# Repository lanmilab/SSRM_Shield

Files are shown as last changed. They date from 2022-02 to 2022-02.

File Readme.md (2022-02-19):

# IoT Solid State Ralay and Power Monitor Shield

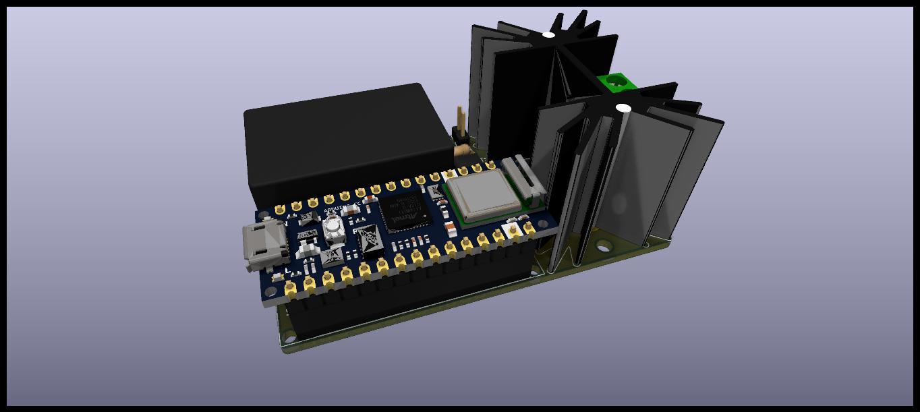
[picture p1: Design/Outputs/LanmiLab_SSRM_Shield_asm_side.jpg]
LanmiLab_SSRM_Shield_asm_side


Shield made specifically for Arduino nano IoT or compatible development board.
- Based on triac transistor with opto-isolated driving to be used for heater or lighting control IoT applications.
- Isolated 2Watts AC/DC converter.
- Integrates AC power monitor ACS71020KMABTR-030B3-I2C.
- One on board NTC temperature sensor, plus header for off-board NTC. 

## License

KiCad design is available but not verified, use on your own resposibility!

THE DESIGN IS PROVIDED "AS IS" AND THE AUTHOR DISCLAIMS ALL WARRANTIES WITH REGARD TO THIS DESIGN INCLUDING ALL IMPLIED WARRANTIES OF MERCHANTABILITY AND FITNESS. IN NO EVENT SHALL THE AUTHOR BE LIABLE FOR ANY SPECIAL, DIRECT, INDIRECT, OR CONSEQUENTIAL DAMAGES OR ANY DAMAGES WHATSOEVER RESULTING FROM LOSS OF USE, DATA OR PROFITS, WHETHER IN AN ACTION OF CONTRACT, NEGLIGENCE OR OTHER TORTIOUS ACTION, ARISING OUT OF OR IN CONNECTION WITH THE USE OR PERFORMANCE OF THIS DESIGN.

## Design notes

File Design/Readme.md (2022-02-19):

# IoT Solid State Ralay and Power Monitor Shield KiCad Design Files

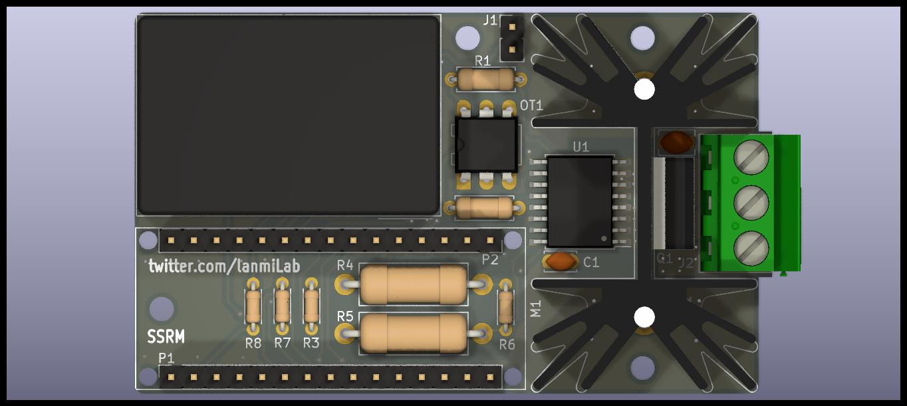
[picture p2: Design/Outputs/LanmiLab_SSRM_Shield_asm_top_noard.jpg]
LanmiLab_SSRM_Shield_asm_top_noard


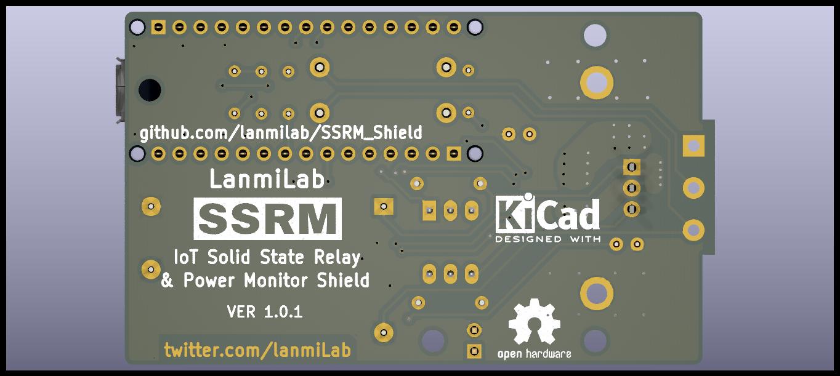
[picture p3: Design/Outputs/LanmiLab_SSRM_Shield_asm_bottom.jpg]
LanmiLab_SSRM_Shield_asm_bottom


Gerber and assembly files available in Outputs directory.

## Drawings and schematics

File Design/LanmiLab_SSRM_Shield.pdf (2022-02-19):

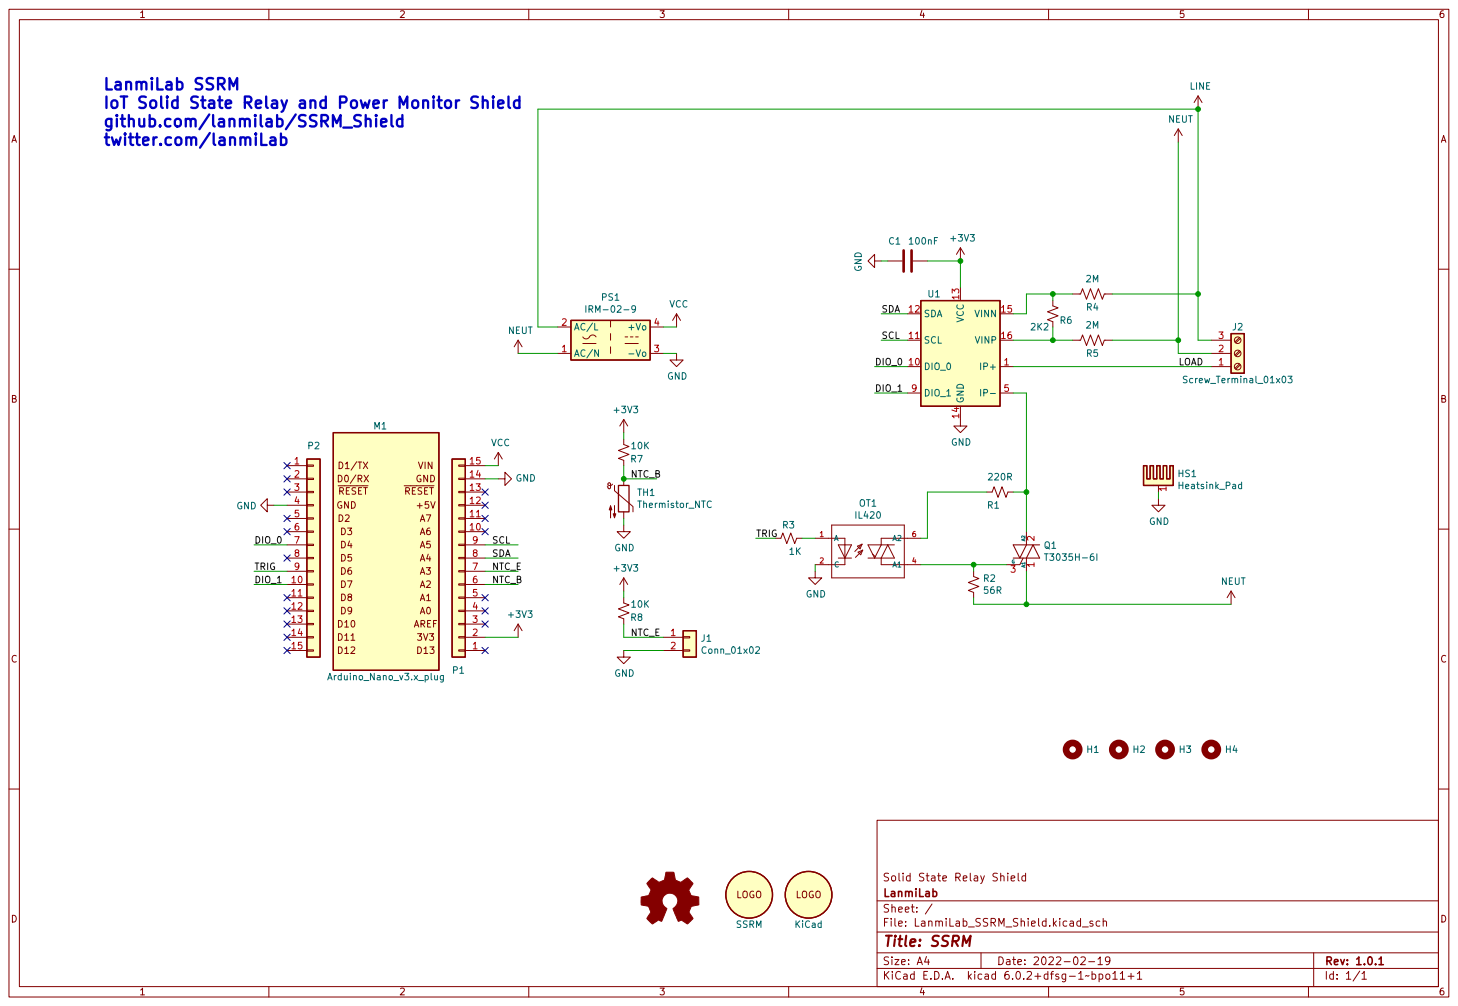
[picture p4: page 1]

DIO_0 DIO_1 LanmiLab SSRM
IoT Solid State Relay and Power Monitor Shield
github.com/lanmilab/SSRM_Shield
twitter.com/lanmiLab

File: LanmiLab_SSRM_Shield.kicad_sch Sheet: / LanmiLab Solid State Relay Shield

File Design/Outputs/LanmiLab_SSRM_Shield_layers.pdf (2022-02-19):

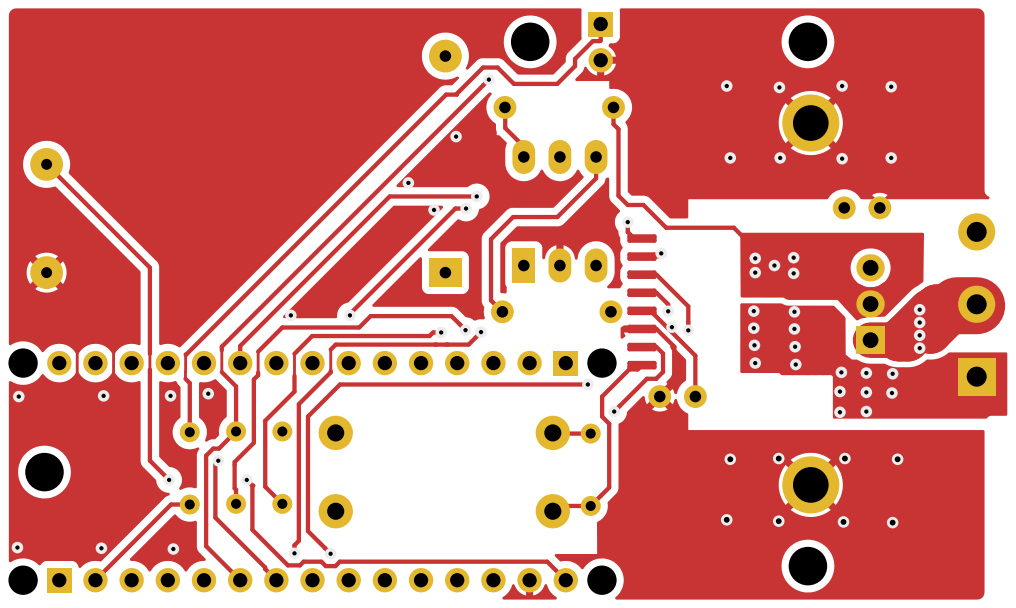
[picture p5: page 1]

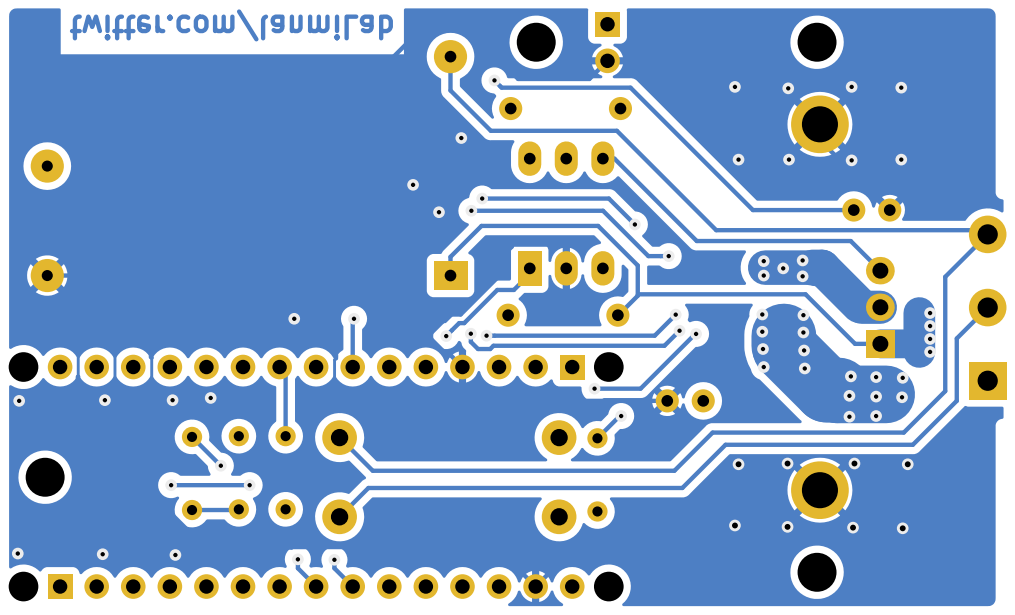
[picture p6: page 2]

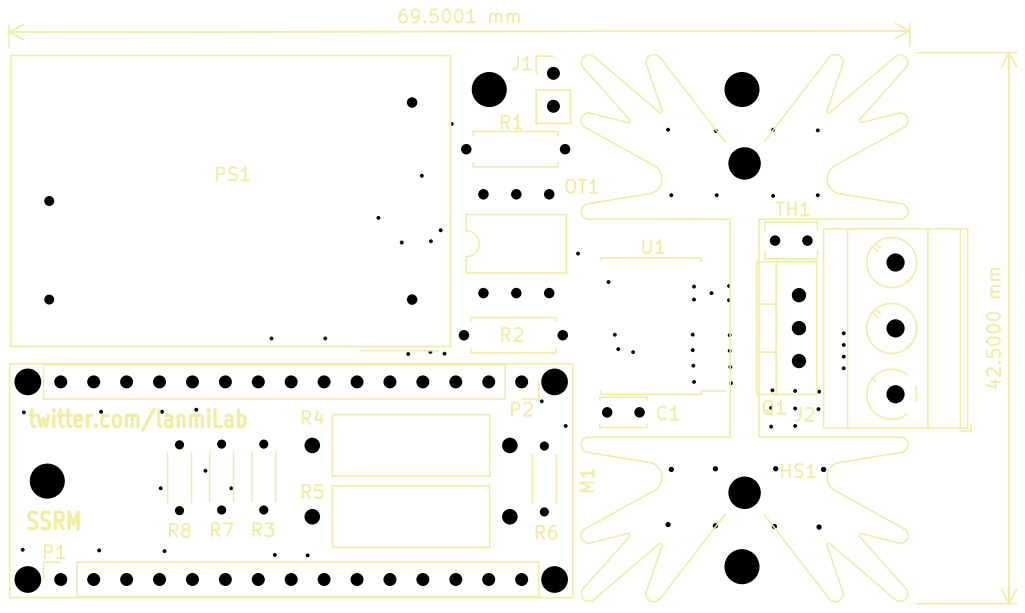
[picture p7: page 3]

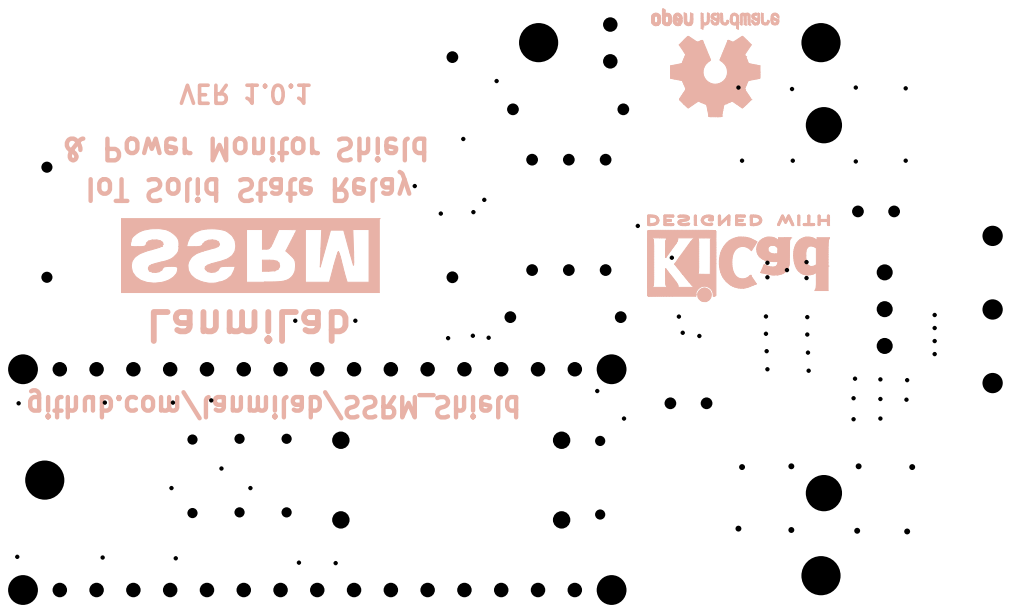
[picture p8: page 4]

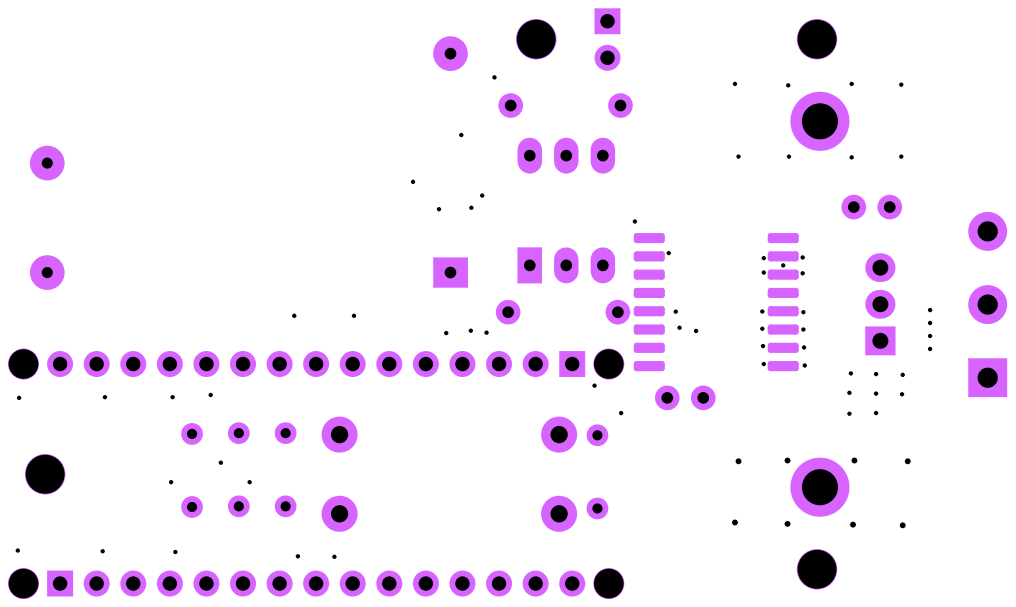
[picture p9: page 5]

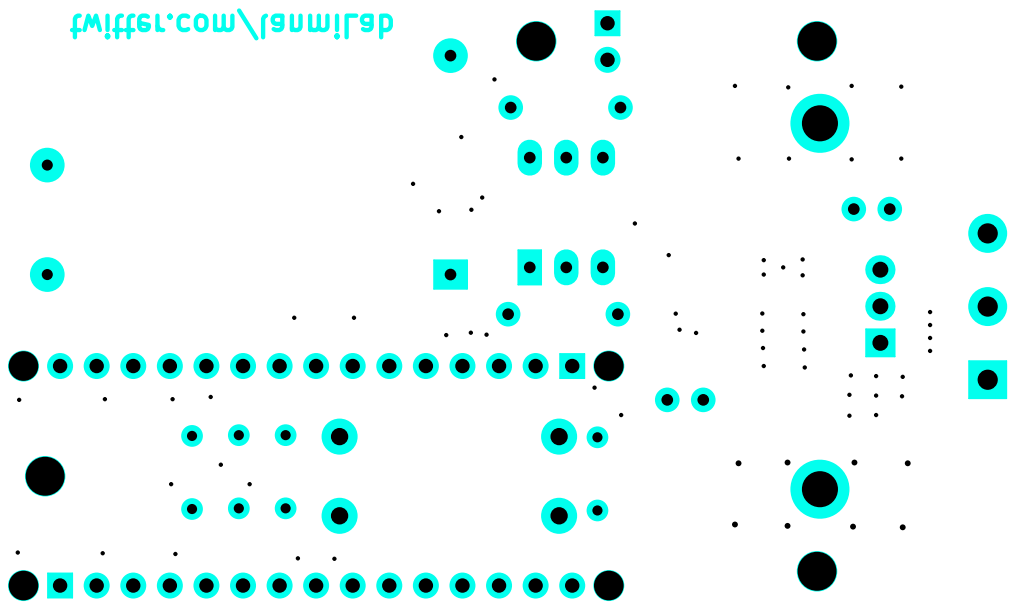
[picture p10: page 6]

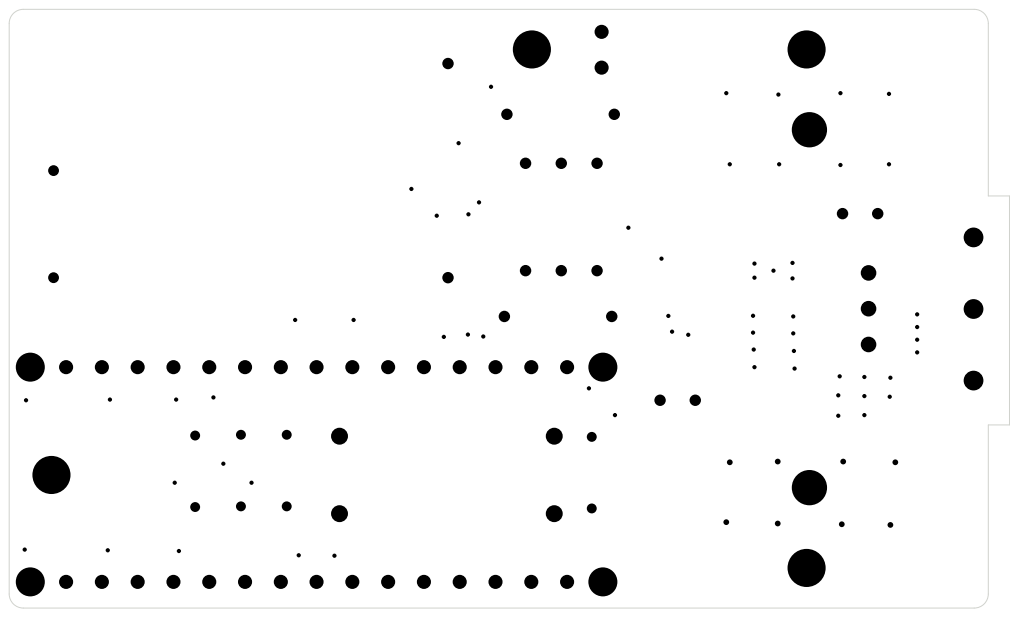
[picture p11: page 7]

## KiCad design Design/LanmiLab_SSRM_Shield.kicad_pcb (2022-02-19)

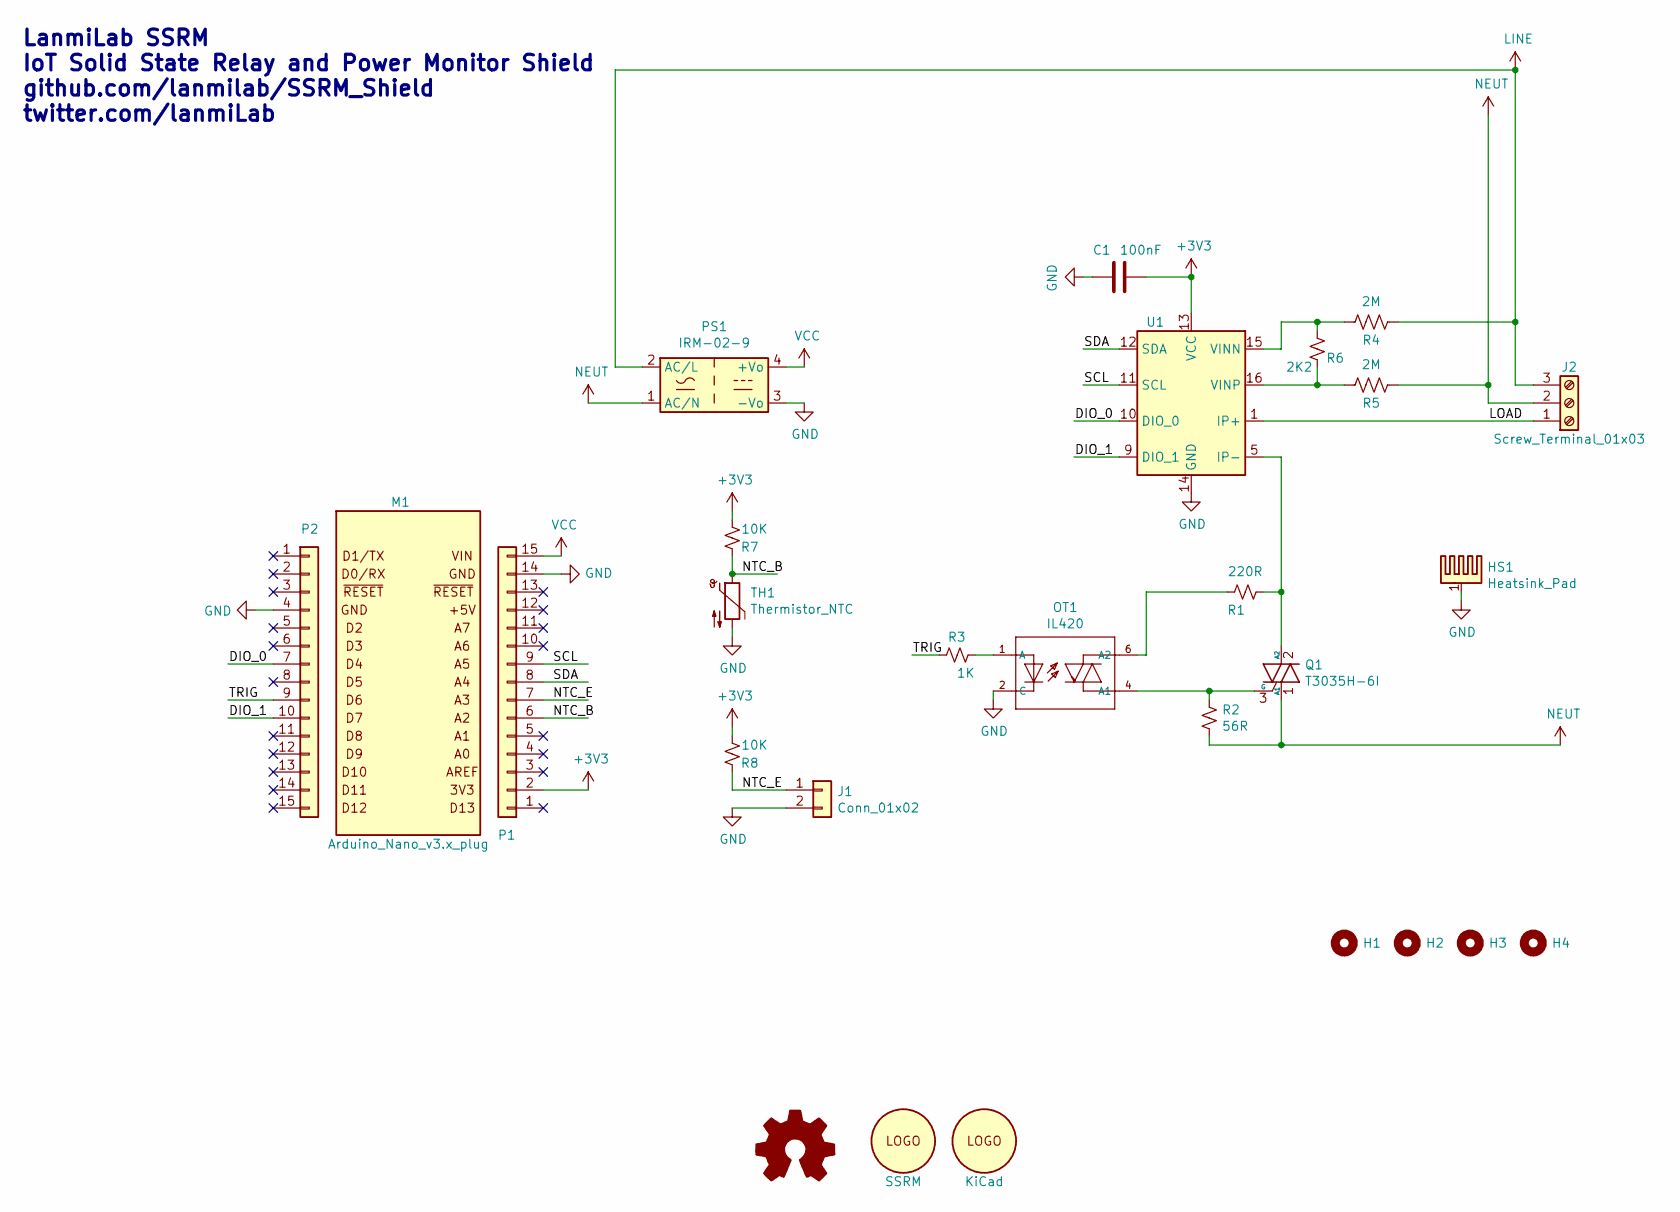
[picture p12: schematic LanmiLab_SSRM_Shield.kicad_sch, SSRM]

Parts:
C1: 100nF; C_Disc_D3.4mm_W2.1mm_P2.50mm; Part Number K104K15X7RF53L2
H1, H2, H3, H4: MountingHole; MountingHole_2.7mm_M2.5
HS1: Heatsink_Pad; Heatsink_Fischer_SK129-STS_42x25mm_2xDrill2.5mm; Part Number FA-T220-25E
J1: Conn_01x02; PinHeader_1x02_P2.54mm_Vertical; Part Number M20-9990245
J2: Screw_Terminal_01x03; TerminalBlock_MetzConnect_Type073_RT02603HBLU_1x03_P5.08mm_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; Part Number MKDS 3/ 3-5,08
LOGO1: Logo_Open_Hardware_Small; OSHW-Logo2_9.8x8mm_SilkScreen
LOGO2: SSRM; ssr
LOGO3: KiCad; KiCad-Logo2_5mm_SilkScreen
M1: Arduino_Nano_v3.x_plug; Arduino_Nano_33_IoT_3D_NoPads
OT1: IL420; DIP-6_W7.62mm_LongPads; Part Number IL420
P1, P2: Conn_01x15; PinSocket_1x15_P2.54mm_Vertical; Part Number PPPC151LFBN-RC
PS1: IRM-02-9; Converter_ACDC_MeanWell_IRM-02-xx_THT; Part Number IRM-02-9
Q1: T3035H-6I; TO-220-3_Vertical; Part Number T3035H-6I
R1: 220R; R_Axial_DIN0207_L6.3mm_D2.5mm_P7.62mm_Horizontal; Part Number MFP1-220R JI
R2: 56R; R_Axial_DIN0207_L6.3mm_D2.5mm_P7.62mm_Horizontal; Part Number MRS25000C5609FCT00
R3: 1K; R_Axial_DIN0204_L3.6mm_D1.6mm_P5.08mm_Horizontal; Part Number LR0204F1K0
R4, R5: 2M; R_Axial_DIN0414_L11.9mm_D4.5mm_P15.24mm_Horizontal; Part Number HVR3700002004FR500
R6: 2K2; R_Axial_DIN0204_L3.6mm_D1.6mm_P5.08mm_Horizontal; Part Number CFR16J2K2
R7, R8: 10K; R_Axial_DIN0204_L3.6mm_D1.6mm_P5.08mm_Horizontal; Part Number CFR16J10K
TH1: Thermistor_NTC; C_Disc_D3.8mm_W2.6mm_P2.50mm; Part Number B57891M0103K000
U1: ACS71020KMABTR-030B3-I2C; SOIC-16W_7.5x10.3mm_P1.27mm; Part Number ACS71020KMABTR-030B3-I2C

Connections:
+3V3: C1.1, P1.2, R7.2, R8.2, U1.13 (VCC)
/DIO_0: P2.7, U1.10 (DIO_0)
/DIO_1: P2.10, U1.9 (DIO_1)
/LOAD: J2.1, U1.1 (IP+), U1.2 (IP+), U1.3 (IP+), U1.4 (IP+)
/NTC_B: P1.6, R7.1, TH1.1
/NTC_E: J1.1, P1.7, R8.1
/SCL: P1.9, U1.11 (SCL)
/SDA: P1.8, U1.12 (SDA)
/TRIG: P2.9, R3.1
GND: C1.2, HS1.1, J1.2, OT1.2 (C), P1.14, P2.4, PS1.3 (-Vo), TH1.2, U1.14 (GND)
LINE: J2.3, PS1.2 (AC/L), R4.1
NEUT: J2.2, PS1.1 (AC/N), Q1.1 (A1), R2.2, R5.1
unnamed: OT1.1 (A), R3.2
unnamed: OT1.4 (A1), Q1.3 (G), R2.1
unnamed: OT1.6 (A2), R1.2
unnamed: Q1.2 (A2), R1.1, U1.5 (IP-), U1.6 (IP-), U1.7 (IP-), U1.8 (IP-)
unnamed: R4.2, R6.1, U1.15 (VINN)
unnamed: R5.2, R6.2, U1.16 (VINP)
VCC: P1.15, PS1.4 (+Vo)

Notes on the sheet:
LanmiLab SSRM IoT Solid State Relay and Power Monitor Shield github.com/lanmilab/SSRM_Shield twitter.com/lanmiLab

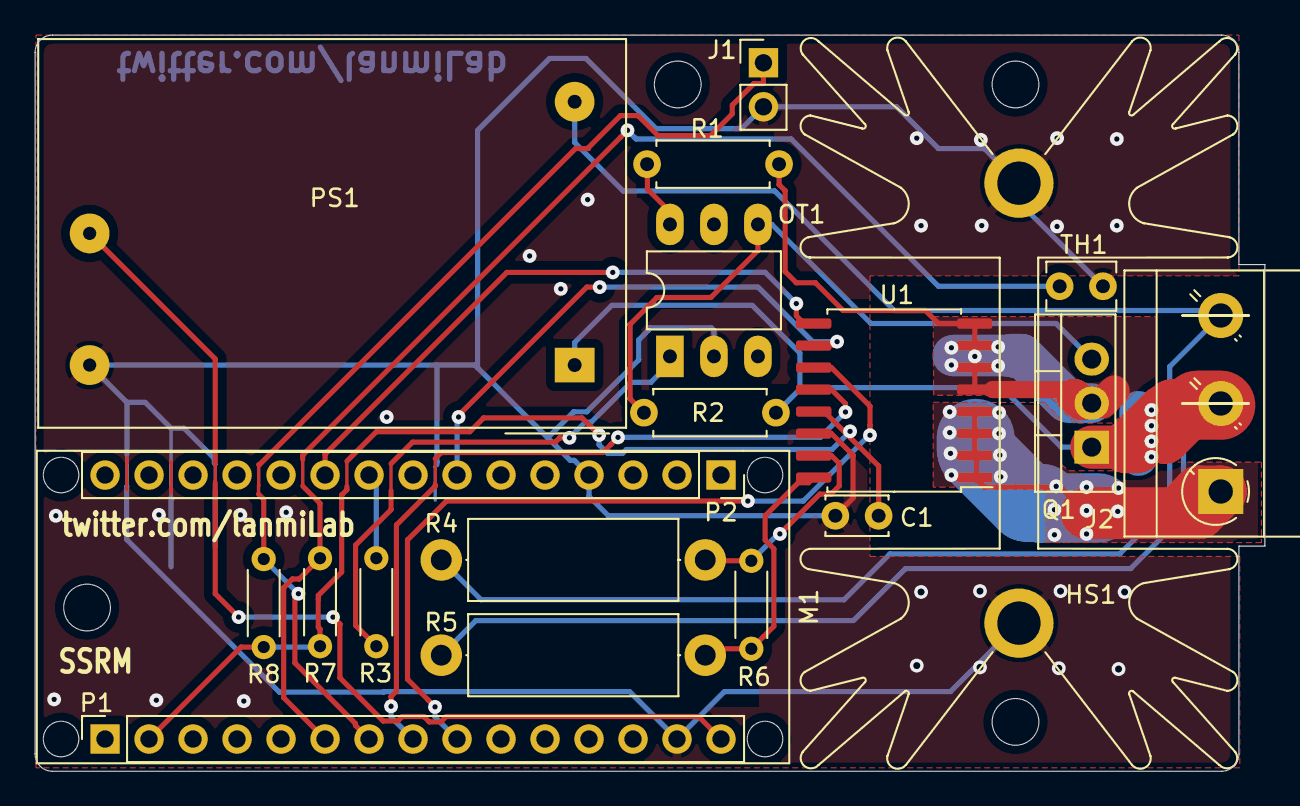
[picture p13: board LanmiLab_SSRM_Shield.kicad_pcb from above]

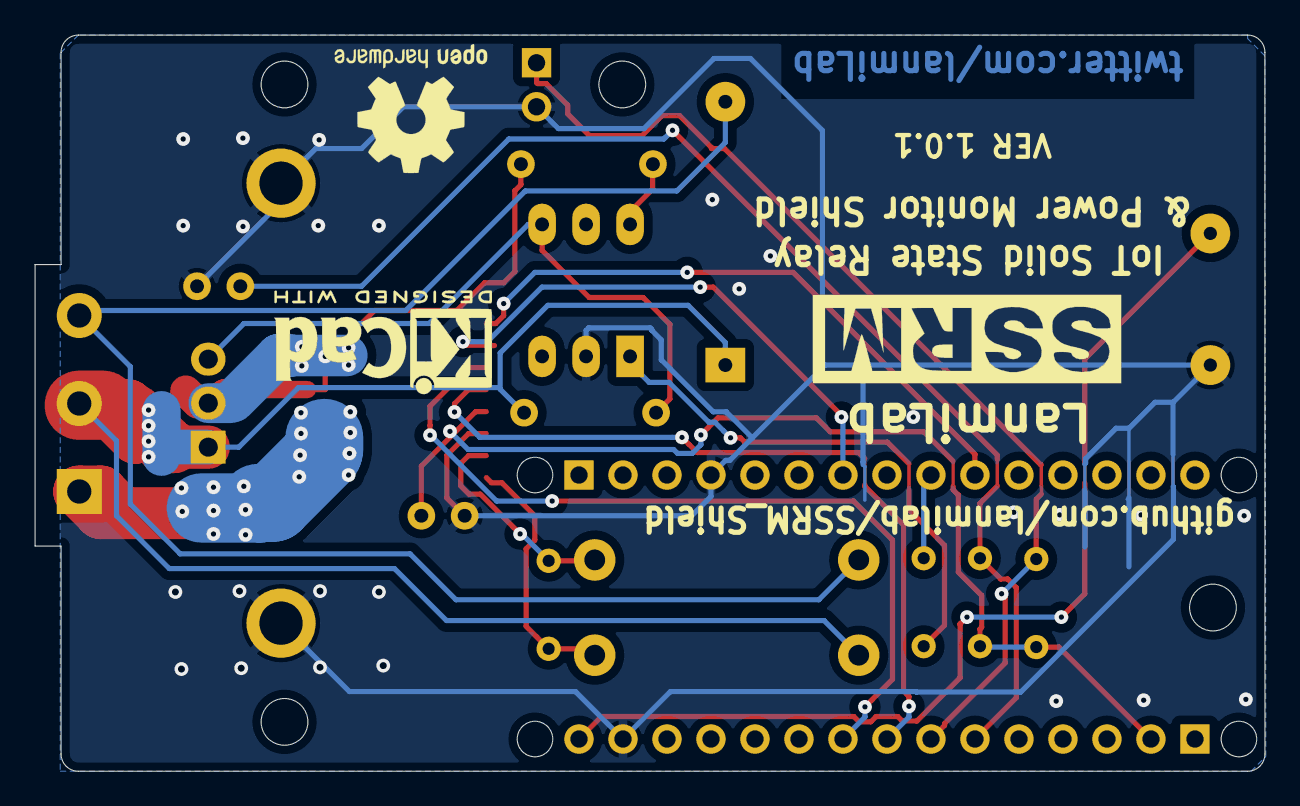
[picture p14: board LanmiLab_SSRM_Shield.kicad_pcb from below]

Board: 2 copper layers, 71.0 x 42.5 mm, 27 parts (3 on the bottom side), 19 nets.
